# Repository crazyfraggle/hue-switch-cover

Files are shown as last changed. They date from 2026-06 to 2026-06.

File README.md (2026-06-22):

# Parametric Hue Buttons light switch cover


Does you house too look like this?

<table>
  <tr>
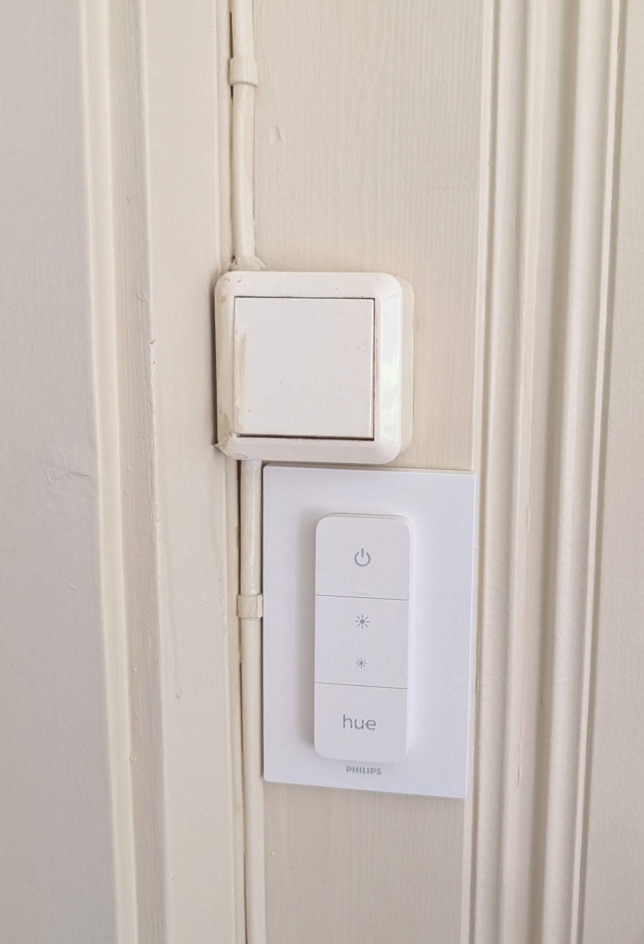
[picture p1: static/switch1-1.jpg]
Old switch with Hue buttons
    <td></td>
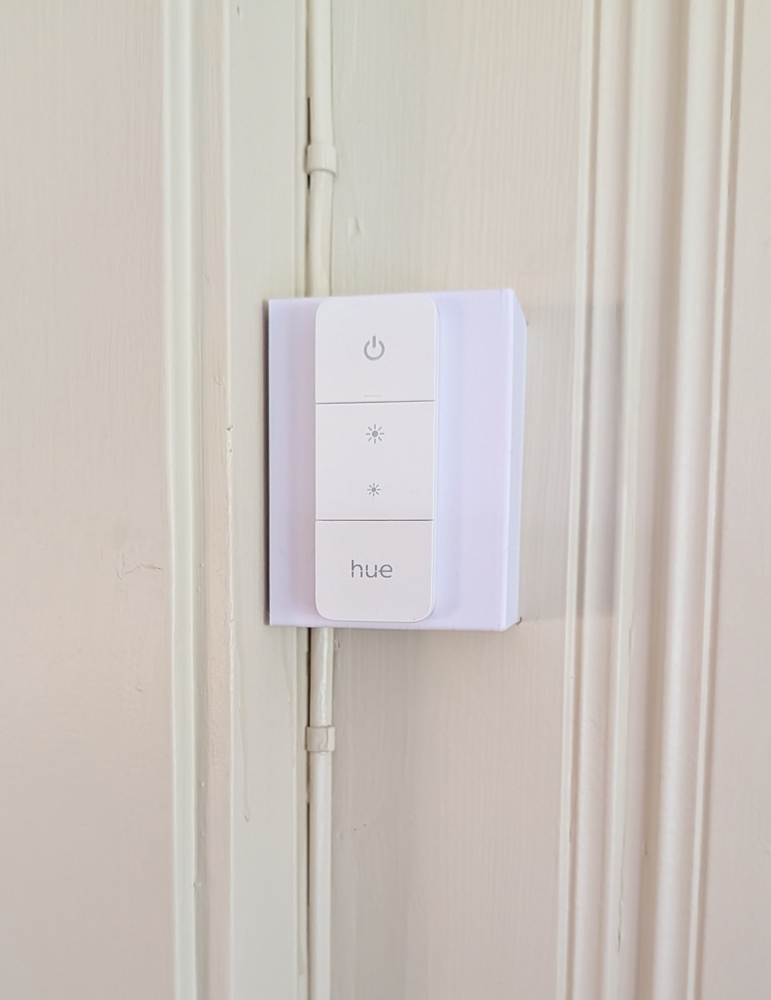
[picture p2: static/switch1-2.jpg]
Covered by Hue buttons
    <td></td>
  </tr>
  <tr>
    <td align="center">Before</td>
    <td align="center">After</td>
  </tr>
</table>

Then this might be for you.

This is a parametric generator for a Philips Hue buttons holder to cover over original light switches.

To hold the Hue buttons in place, magnets or some metal need to be glued to the back of the magnet holder strip. I use double sided tape for this so far with a couple of 9mm magnets, but a bit of metal like on the original holders from Philips should also work well, like a washer. If you use magnets, make sure to get the polarization right before gluing them on, the Hue buttons have two internal magnets with opposing polarization.

## Features

* Parametric to allow for cables and door frame cutouts, and a variety of switch sizes
* Poke-through hole behind the Hue buttons to allow access to the old switch when needed
* Wall mount can be fastened with screws or double sided tape
  * **If your cables are hidden, I recommend using tape**

## Parameters

* Size of underlying box
* Cable cutouts for each corner
* Removal of walls on either side for buttons that are placed in corners
* Door frame cutout on either side for buttons next to door frames

## Full assembly example

<table>
  <tr>
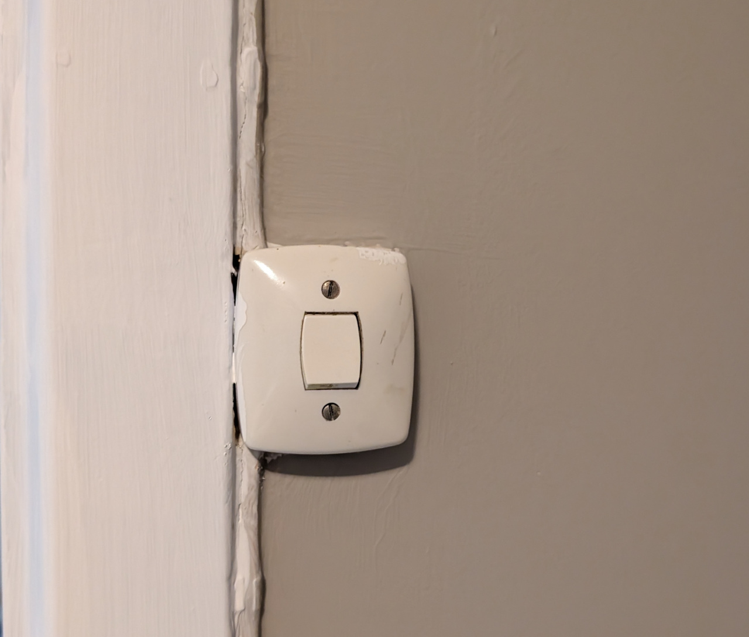
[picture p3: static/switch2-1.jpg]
Old switch
    <td></td>
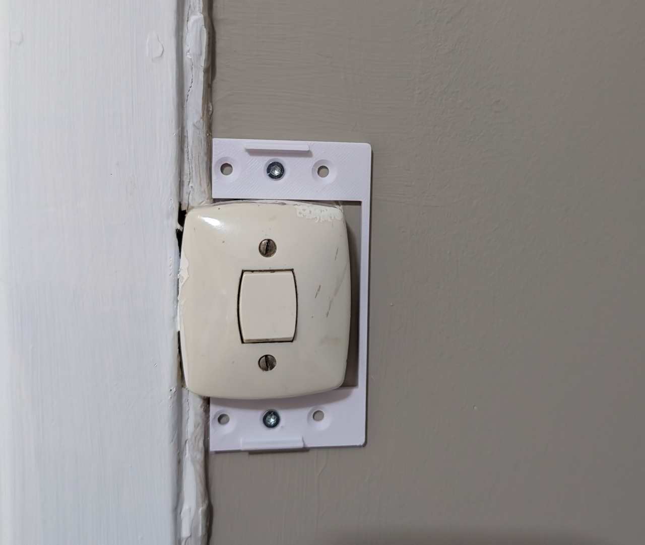
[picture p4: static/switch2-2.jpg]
Backplate mounted
    <td></td>
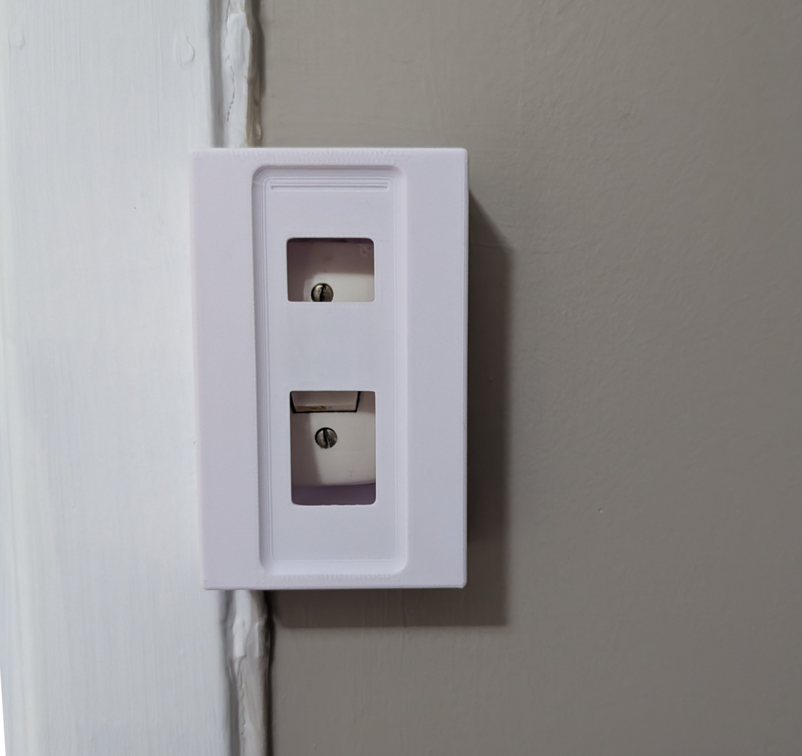
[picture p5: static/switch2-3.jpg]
Cover mounted
    <td></td>
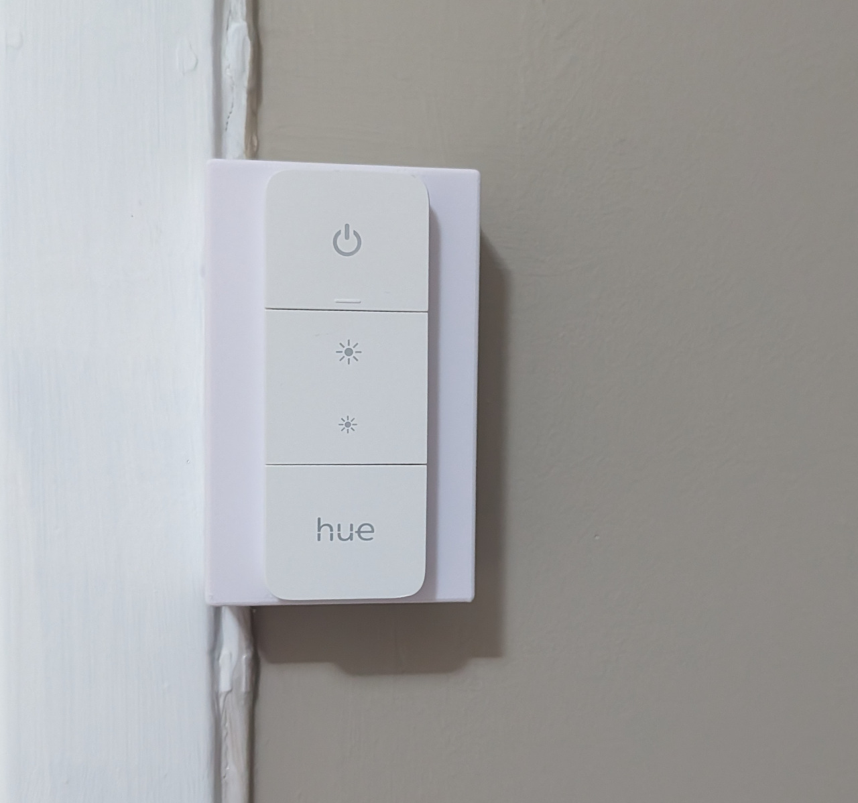
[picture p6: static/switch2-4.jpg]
Hue buttons attached
    <td></td>
  </tr>
  <tr>
    <td align="center">Old switch</td>
    <td align="center">Backplate mounted</td>
    <td align="center">Cover mounted</td>
    <td align="center">Hue buttons attached</td>
  </tr>
</table>

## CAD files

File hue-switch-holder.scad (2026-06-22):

// Parameters

/* [Original switch] */
old_button_box_width = 50;
old_button_box_height = 50;
old_button_box_depth = 30;

/* [Box Wall] */
wall_thickness = 3; // [2.6:0.2:4]
top_thickness = wall_thickness;
drop_left_wall = false;
drop_right_wall = false;
door_frame_adjust_left = 0;
door_frame_adjust_right = 0;

/* [Mounting plate] */
mounting_plate_thickness = 3;
grip_height = 4;

/* [Cable holes] */
top_left_cable_hole_diameter = 0;
top_right_cable_hole_diameter = 0;
bottom_left_cable_hole_diameter = 0;
bottom_right_cable_hole_diameter = 0;

/* [Buttons] */
inset_depth = 2;
//hue_buttons_offset_from_center = 0;

/* [Text] */
//text = "Let there be light";

/* [Hidden] */
hue_switch_width = 35.2;
hue_switch_height = 92.3;
hue_switch_thickness = 11.3;
hue_switch_rounding_r = 4;
hue_switch_inset_depth = 0.8;
hue_switch_inset_offset_top = 5.5;
hue_switch_inset_thickness = 1;
hue_switch_inset_width = 25;
hue_switch_magnet_offset_top = 40;
hue_switch_cutout_tolerance = 1;
$fn = 90;

box_dims = [
  max(old_button_box_width, hue_switch_width) + 2 * wall_thickness,
  max(old_button_box_height, hue_switch_height) + 2 * wall_thickness,
  old_button_box_depth + top_thickness - mounting_plate_thickness,
];
inner_box_dims = box_dims - [2, 2, 0] * wall_thickness - [0, 0, top_thickness];

union() {
  difference() {
    outer_box();
    inner_box();
    hue_switch_cutout();
    wall_removal_cutout();
    wire_holes_cutout();
    button_peek_hole();
    translate([0, 0, (box_dims[2] - grip_height) / -2])
      scale([1.01, 1, 1]) // Slight scaling to give some sideways slack
        mounting_grips();
  }
  // Need to add at the end to avoid it being cut out.
  magnet_holder();
}

translate([box_dims[0] + 10, 0, 0]) mounting_plate();

module mounting_plate() {
  wt = wall_thickness;
  dims = [box_dims[0], box_dims[1], mounting_plate_thickness];

  difference() {
    hull() {
      for (xm = [-2:4:2], ym = [-2:4:2])
        translate([(dims[0] - wt) / xm, (dims[1] - wt) / ym, 0])
          cylinder(h=dims[2], d=wt, center=true);
    }
    cube([old_button_box_width, old_button_box_height, dims[2]] + [1, 1, 1], center=true);
    // Wall cutaway
    if (drop_left_wall || door_frame_adjust_left > 0)
      translate([(dims[0] - wt) / -2, 0, 0])
        cube([wt, dims[1], dims[2]], center=true);
    if (drop_right_wall || door_frame_adjust_right > 0)
      translate([(dims[0] - wt) / 2, 0, 0])
        cube([wt, dims[1], dims[2]], center=true);
    // Wire cutaway
    translate([0, 0, box_dims[2] / 2 + mounting_plate_thickness])
      wire_holes_cutout();
    // TODO: Screw mount cutaway
    for (xm = [-1:1], ym = [-2:4:2])
      translate([box_dims[0] / 4 * xm, (box_dims[1] - (box_dims[1] - old_button_box_height) / 2) / ym, 0])
        union() {
          cylinder(h=dims[2], d=4, center=true);
          translate([0, 0, dims[2] / 4]) #cylinder(h=dims[2] / 2, d1=4, d2=8, center=true);
        }
  }
  // Mounting grip
  translate([0, 0, (mounting_plate_thickness + grip_height) / 2])
    mounting_grips();
}

module mounting_grips() {
  translate([0, (box_dims[1] - wall_thickness) / 2, 0]) mirror([0, 1, 0]) mounting_grip();
  translate([0, (box_dims[1] - wall_thickness) / -2, 0]) mounting_grip();
}

module mounting_grip() {
  grip_wall = wall_thickness / 3;
  grip = grip_wall * 2;
  width = 20;
  height = grip_height;

  union() {
    translate([0, (wall_thickness - grip_wall) / 2, 0])
      cube([width, grip_wall, height], center=true);
    translate([0, (wall_thickness - grip) / 2, (height - grip) / 2])
      rotate([0, 90, 0])
        cylinder(d=grip, h=width, center=true, $fn=4);
    translate([0, (wall_thickness - grip_wall) / 2, height / -2])
      rotate([0, 90, 0])
        cylinder(d=wall_thickness, h=width, center=true, $fn=4);
  }
}

module outer_box() {
  wt = wall_thickness;
  tt = top_thickness;

  hull() {
    for (xm = [-2:4:2], ym = [-2:4:2]) {
      translate([(box_dims[0] - wt) / xm, (box_dims[1] - wt) / ym, (box_dims[2] - tt) / -2])
        cylinder(h=wt, d=wt, center=true);
      translate([(box_dims[0] - wt) / xm, (box_dims[1] - wt) / ym, (box_dims[2] - tt) / 2])
        sphere(d=wt);
    }
  }
}

module inner_box() {
  wt = wall_thickness;
  tt = top_thickness;

  hull() {
    for (xm = [-2:4:2], ym = [-2:4:2]) {
      translate(
        [
          (inner_box_dims[0] - wt) / xm,
          (inner_box_dims[1] - wt) / ym,
          (inner_box_dims[2]) / -2 - tt,
        ]
      )
        cylinder(h=wt, d=wt, center=true);
      translate(
        [
          (inner_box_dims[0] - wt) / xm,
          (inner_box_dims[1] - wt) / ym,
          (inner_box_dims[2]) / 2 - tt,
        ]
      )
        sphere(d=wt);
    }
  }
}

module hue_switch_cutout() {
  translate([0, 0, (box_dims[2] + hue_switch_thickness) / 2 - inset_depth])
    hue_switch();
}

module hue_switch() {
  r = hue_switch_rounding_r;
  center_width = hue_switch_width - 2 * r;
  center_height = hue_switch_height - 2 * r;
  center_depth = hue_switch_thickness - 2 * r;

  union() {
    hull() {
      for (x = [-2:4:2], y = [-2:4:2]) {
        translate([(center_width - 0.8) / x, (center_height - 0.8) / y, (center_depth) / -2])
          sphere(r=hue_switch_rounding_r);
        translate([(center_width) / x, (center_height) / y, (center_depth) / 2])
          cylinder(h=hue_switch_rounding_r * 2, r=hue_switch_rounding_r, center=true);
      }
    }
    translate([0, hue_switch_height / 2 - hue_switch_inset_offset_top, -hue_switch_thickness / 2])
      hull() {
        translate([hue_switch_inset_width / -2, 0, 0])
          sphere(d=hue_switch_inset_thickness);
        translate([hue_switch_inset_width / 2, 0, 0])
          sphere(d=hue_switch_inset_thickness);
      }
  }
}

module wire_holes_cutout() {
  translate([0, 0, box_dims[2] / -2 - mounting_plate_thickness]) {
    translate([inner_box_dims[0] / -2, box_dims[1] / 2, 0])
      cable_hole(top_left_cable_hole_diameter);
    translate([inner_box_dims[0] / 2, box_dims[1] / 2, 0])
      cable_hole(top_right_cable_hole_diameter, left=false);
    translate([inner_box_dims[0] / -2, box_dims[1] / -2, 0])
      cable_hole(bottom_left_cable_hole_diameter);
    translate([inner_box_dims[0] / 2, box_dims[1] / -2, 0])
      cable_hole(bottom_right_cable_hole_diameter, left=false);
  }
}

// TODO: Make cable hole be a square that is rounded only on the inner side, instead of a cylinder?
module cable_hole(d, left = true) {
  if (d > 0)
    rotate([90, 0, 0])
      cylinder(h=box_dims[1], r=d, center=true, $fn=45);
}

// This handles both door frame adjustment and side wall removal
module wall_removal_cutout() {
  dfal = drop_left_wall ? box_dims[2] : max(0, door_frame_adjust_left - mounting_plate_thickness);
  dfar = drop_right_wall ? box_dims[2] : max(0, door_frame_adjust_right - mounting_plate_thickness);

  translate([(box_dims[0] - wall_thickness) / -2, 0, (box_dims[2] - dfal) / -2])
    cube([wall_thickness, box_dims[1], dfal], center=true);
  translate([(box_dims[0] - wall_thickness) / 2, 0, (box_dims[2] - dfar) / -2])
    cube([wall_thickness, box_dims[1], dfar], center=true);
}

module button_peek_hole() {
  r = 1;
  center_width = hue_switch_width - 4 * hue_switch_rounding_r - 2 * r;
  center_height = old_button_box_height - 2 * r;
  hull() {
    for (x = [-2:4:2], y = [-2:4:2]) {
      translate([(center_width) / x, (center_height) / y, 0])
        cylinder(h=old_button_box_depth + wall_thickness, r=r, center=true, $fn=45);
    }
  }
}

module magnet_holder() {
  width = old_button_box_width;
  height = 20;
  depth = 0.6;

  translate([0, hue_switch_height / 2 - hue_switch_magnet_offset_top, (box_dims[2]) / 2 - inset_depth - depth / 2])
    cube([width, height, depth], center=true);
}

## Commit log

2026-06-20 Initial files
    [hue-switch-holder.scad]
2026-06-22 SCAD formatted
    [hue-switch-holder.scad]

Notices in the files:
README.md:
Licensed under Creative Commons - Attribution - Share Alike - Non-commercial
